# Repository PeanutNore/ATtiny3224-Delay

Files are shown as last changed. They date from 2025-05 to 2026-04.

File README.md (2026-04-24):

# ATtiny3224-Delay
A Digital Delay Pedal for guitar based on the ATtiny3224 microcontroller and 23LC512 SRAM

I have included two different circuit designs that are each compatible with the code in this repository.
I recommend the "Business Card Delay" circuit for those comfortable designing their own PCB as this is 
a newer, optimized design that provides better audio quality with fewer components.
If you don't want to design your own PCB you can order copies of version 1.0 using the included Gerber files.

This program, PCB design, and associated schematics are distributed in the hope that they will be useful, but WITHOUT ANY WARRANTY; without even the implied warranty of MERCHANTABILITY or FITNESS FOR A PARTICULAR PURPOSE.

ATtinyDelay

To use this software you will need:

- A complete and working ATtiny Delay circuit (or the version of the circuit on my business card)
    - Refer to the included schematic (or just populate the components on the business card)
    - Gerber files for ordering PCBs are included in ATTiny_Delay_Pedal.zip. I have had success using JLCPCB. This is not an endorsement, use whatever PCB vendor you prefer.
- Arduino IDE version 1.8.19 or greater
- megaTinyCore (https://github.com/SpenceKonde/megaTinyCore) for ATtiny3224 support
- A UPDI programmer (I recommend the UPDI Friend from Adafruit)

This is a basic digital delay pedal for guitar that aims achieve high audio quality at minimal cost compared to other DIY delay options such as using an FV-1 or PT2399.
It provides 12 bit sample depth at greater than 24khz sample rate, which results in no loss of quality when used with typical guitar and amp rigs.

 * Copyright 2025-2026 Samuel Brown. All Rights Reservered.
 * 
 * Licensed under Creative Commons CC-BY-NC-SA 4.0
 * https://creativecommons.org/licenses/by-nc-sa/4.0/
 * 
 * You are free to share and adapt this software for non-
 * commercial purposes provided that you give appropriate 
 * credit and attribution, and distribute your contributions 
 * under the same CC-BY-NC-SA license.
 * 
 * For commercial licensing contact sam.brown.rit08@gmail.com

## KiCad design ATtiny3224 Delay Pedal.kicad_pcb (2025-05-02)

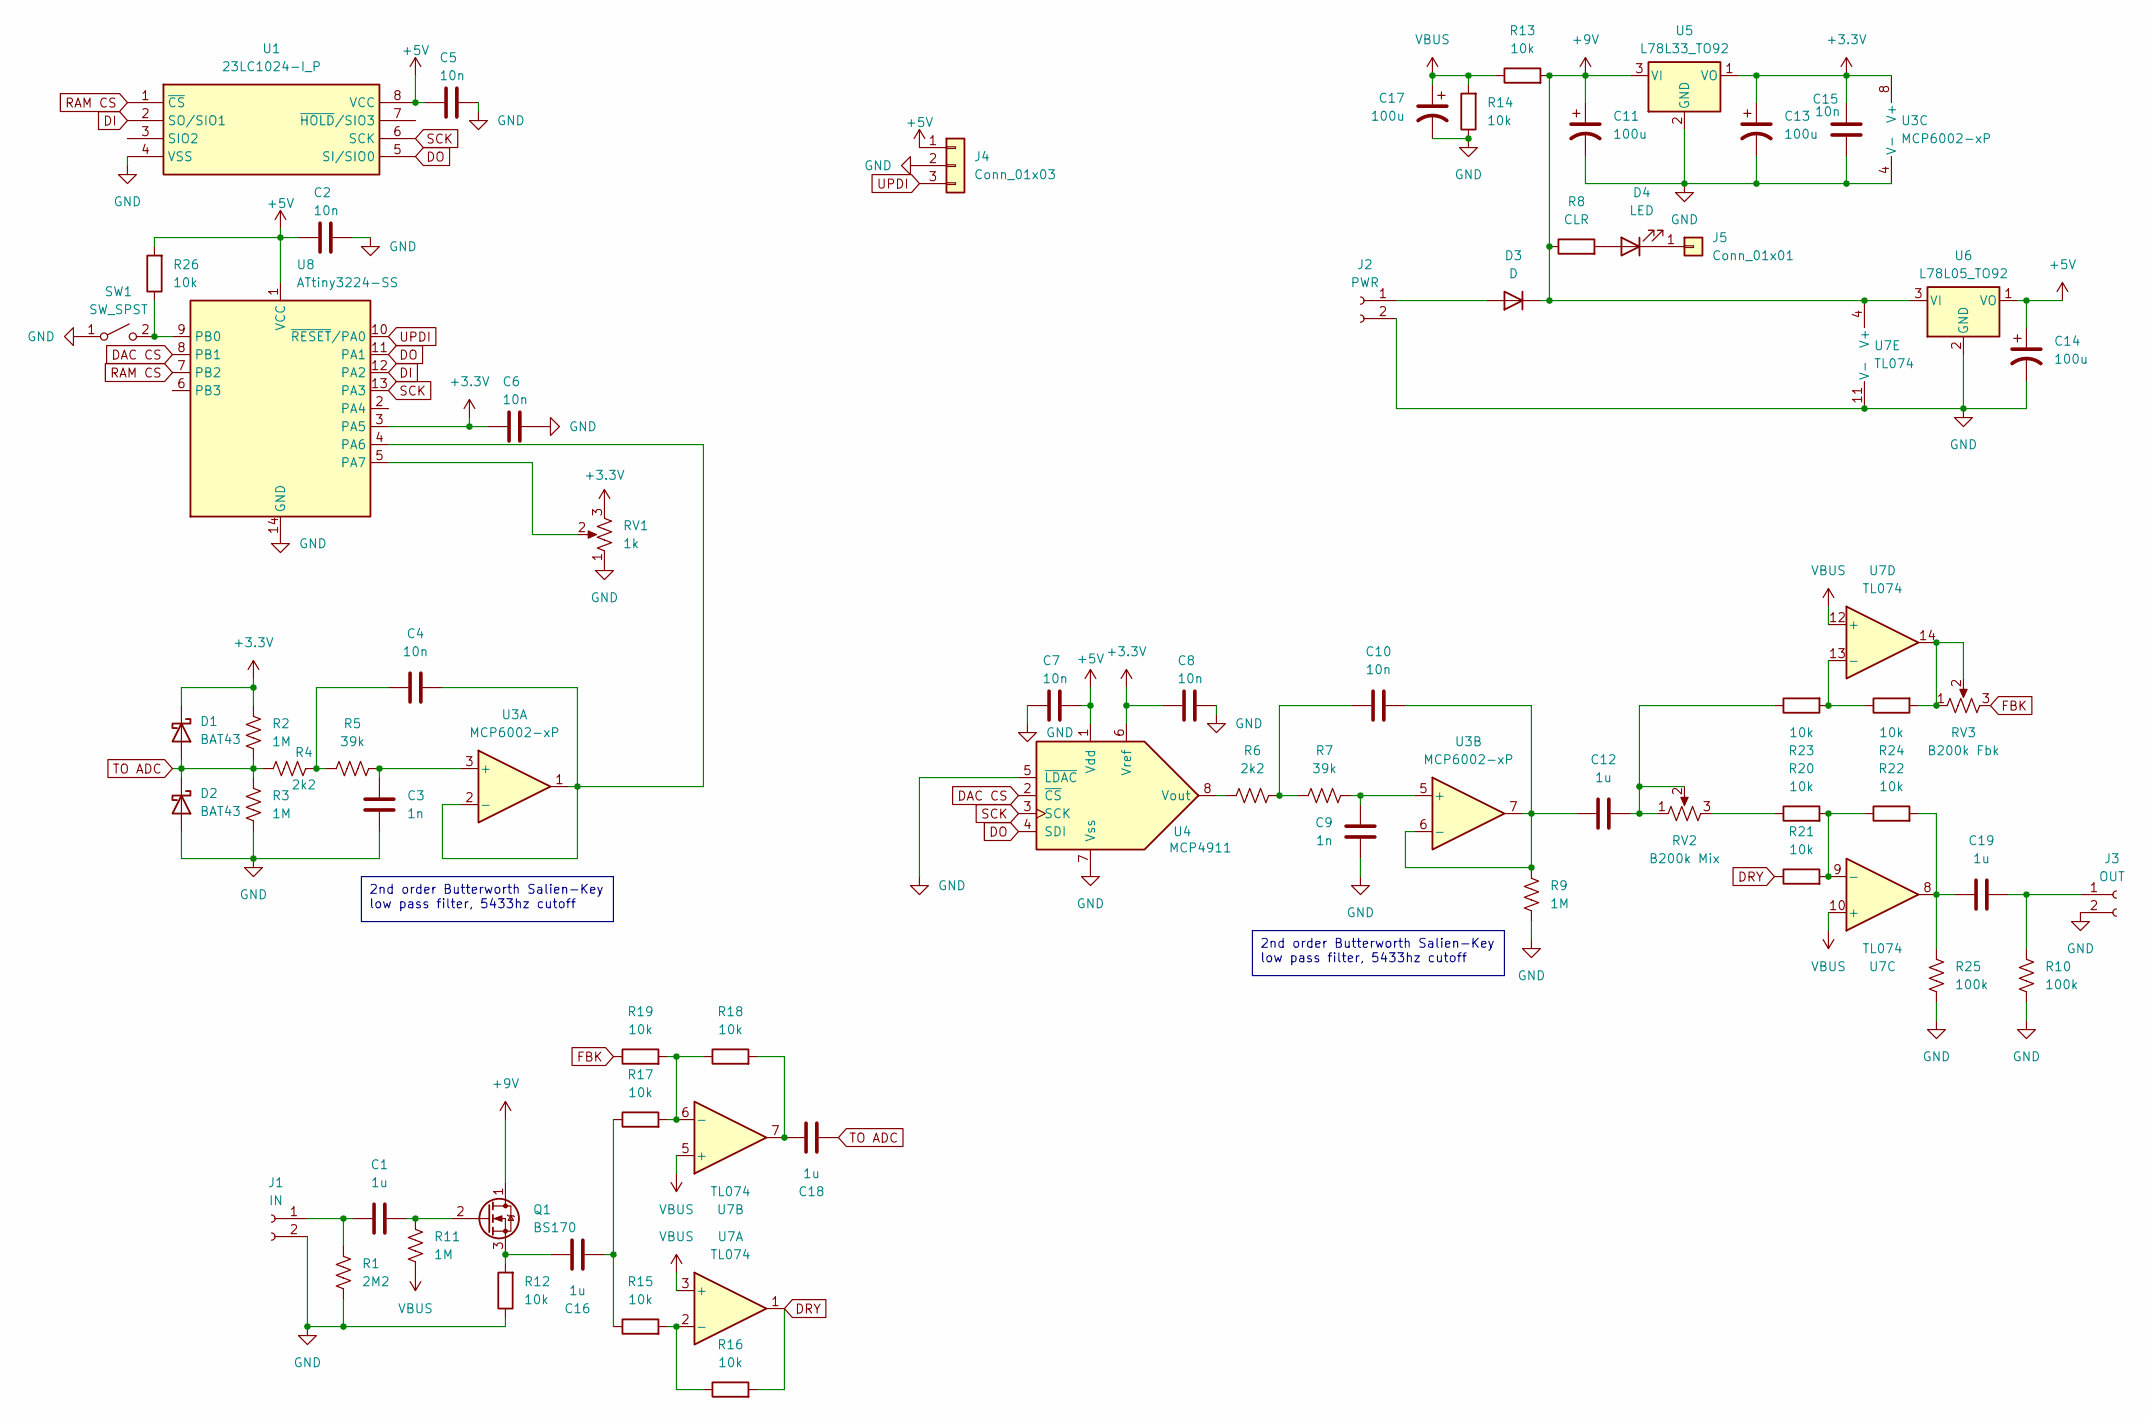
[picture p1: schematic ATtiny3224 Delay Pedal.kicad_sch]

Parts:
C1, C12, C16, C18, C19: 1u; C_Rect_L7.0mm_W4.5mm_P5.00mm
C2, C4, C5, C6, C7, C8, C10, C15: 10n; C_Rect_L4.0mm_W2.5mm_P2.50mm
C3, C9: 1n; C_Rect_L4.0mm_W2.5mm_P2.50mm
C11, C13, C14, C17: 100u; CP_Radial_D6.3mm_P2.50mm
D1, D2: BAT43; D_DO-35_SOD27_P7.62mm_Horizontal
D3: D; D_DO-35_SOD27_P7.62mm_Horizontal
D4: LED; LED_D3.0mm
J1: IN; PinHeader_1x02_P2.54mm_Vertical
J2: PWR; PinHeader_1x02_P2.54mm_Vertical
J3: OUT; PinHeader_1x02_P2.54mm_Vertical
J4: Conn_01x03; PinHeader_1x03_P2.54mm_Vertical
J5: Conn_01x01; PinHeader_1x01_P2.54mm_Vertical
Q1: BS170; TO-92_Inline
R1: 2M2; R_Axial_DIN0207_L6.3mm_D2.5mm_P7.62mm_Horizontal
R2, R3, R9, R11: 1M; R_Axial_DIN0207_L6.3mm_D2.5mm_P7.62mm_Horizontal
R4, R6: 2k2; R_Axial_DIN0207_L6.3mm_D2.5mm_P7.62mm_Horizontal
R5, R7: 39k; R_Axial_DIN0207_L6.3mm_D2.5mm_P7.62mm_Horizontal
R8: CLR; R_Axial_DIN0207_L6.3mm_D2.5mm_P7.62mm_Horizontal
R10, R25: 100k; R_Axial_DIN0207_L6.3mm_D2.5mm_P7.62mm_Horizontal
R12, R13, R14, R15, R16, R17, R18, R19, R20, R21, R22, R23, R24, R26: 10k; R_Axial_DIN0207_L6.3mm_D2.5mm_P7.62mm_Horizontal
RV1: 1k; RV16AF-41
RV2: B200k Mix; RV16AF-41
RV3: B200k Fbk; RV16AF-41
SW1: SW_SPST; PinHeader_1x03_P2.54mm_Vertical
U1: 23LC1024-I_P; SOIC-8_3.9x4.9mm_P1.27mm; Mouser Part Number 579-23LC1024-I/P
U3: MCP6002-xP; SOIC-8_3.9x4.9mm_P1.27mm
U4: MCP4911; SOIC-8_3.9x4.9mm_P1.27mm
U5: L78L33_TO92; TO-92_Inline
U6: L78L05_TO92; TO-92_Inline
U7: TL074; SOIC-14_3.9x8.7mm_P1.27mm
U8: ATtiny3224-SS; SOIC-14_3.9x8.7mm_P1.27mm

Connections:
+3.3V: C6.2, C8.2, C13.1, C15.1, D1.1 (K), R2.1, RV1.3, U3.8 (V+), U4.6 (Vref), U5.1 (VO), U8.3 (PA5)
+5V: C2.2, C5.2, C7.1, C14.1, J4.1, R26.2, U1.8 (VCC), U4.1 (Vdd), U6.1 (VO), U8.1 (VCC)
+9V: C11.1, D3.1 (K), Q1.1 (D), R8.1, R13.2, U5.3 (VI), U6.3 (VI), U7.4 (V+)
DAC CS: U4.2 (~CS), U8.8 (PB1)
DI: U1.2 (SO/SIO1), U8.12 (PA2)
DO: U1.5 (SI/SIO0), U4.4 (SDI), U8.11 (PA1)
DRY: R16.2, R21.1, U7.1
FBK: R19.1, RV3.3
GND: C2.1, C3.2, C5.1, C6.1, C7.2, C8.1, C9.2, C11.2, C13.2, C14.2, C15.2, C17.2, D2.2 (A), J1.2, J2.2, J3.2, J4.2, R1.2, R3.2, R9.2, R10.2, R12.1, R14.1, R25.2, RV1.1, SW1.1 (A), U1.4 (VSS), U3.4 (V-), U4.5 (~LDAC), U4.7 (Vss), U5.2 (GND), U6.2 (GND), U7.11 (V-), U8.14 (GND)
unnamed: C4.1, R4.2, R5.1
unnamed: C10.1, R6.2, R7.1
unnamed: C12.2, R23.1, RV2.1, RV2.2
unnamed: C16.2, R15.1, R17.1
unnamed: C18.1, R18.2, U7.7
unnamed: C19.1, R22.2, R25.1, U7.8
unnamed: D3.2 (A), J2.1
unnamed: D4.2 (A), R8.2
unnamed: D4.1 (K), J5.1
unnamed: C1.1, J1.1, R1.1
unnamed: C19.2, J3.1, R10.1
unnamed: C1.2, Q1.2 (G), R11.1
unnamed: C16.1, Q1.3 (S), R12.2
unnamed: R20.1, RV2.3
unnamed: R24.2, RV3.1, RV3.2, U7.14
unnamed: R26.1, SW1.2 (B), U8.9 (PB0)
unnamed: C3.1, R5.2, U3.3 (+)
unnamed: C4.2, U3.1, U3.2 (-), U8.4 (PA6)
unnamed: C9.1, R7.2, U3.5 (+)
unnamed: C10.2, C12.1, R9.1, U3.6 (-), U3.7
unnamed: R6.1, U4.8 (Vout)
unnamed: R15.2, R16.1, U7.2 (-)
unnamed: R17.2, R18.1, R19.2, U7.6 (-)
unnamed: R20.2, R21.2, R22.1, U7.9 (-)
unnamed: R23.2, R24.1, U7.13 (-)
unnamed: RV1.2, U8.5 (PA7)
RAM CS: U1.1 (~CS), U8.7 (PB2)
SCK: U1.6 (SCK), U4.3 (SCK), U8.13 (PA3)
TO ADC: C18.2, D1.2 (A), D2.1 (K), R2.2, R3.1, R4.1
UPDI: J4.3, U8.10 (~RESET/PA0)
VBUS: C17.1, R11.2, R13.1, R14.2, U7.3 (+), U7.5 (+), U7.10 (+), U7.12 (+)

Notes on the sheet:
2nd order Butterworth Salien-Key low pass filter, 5433hz cutoff

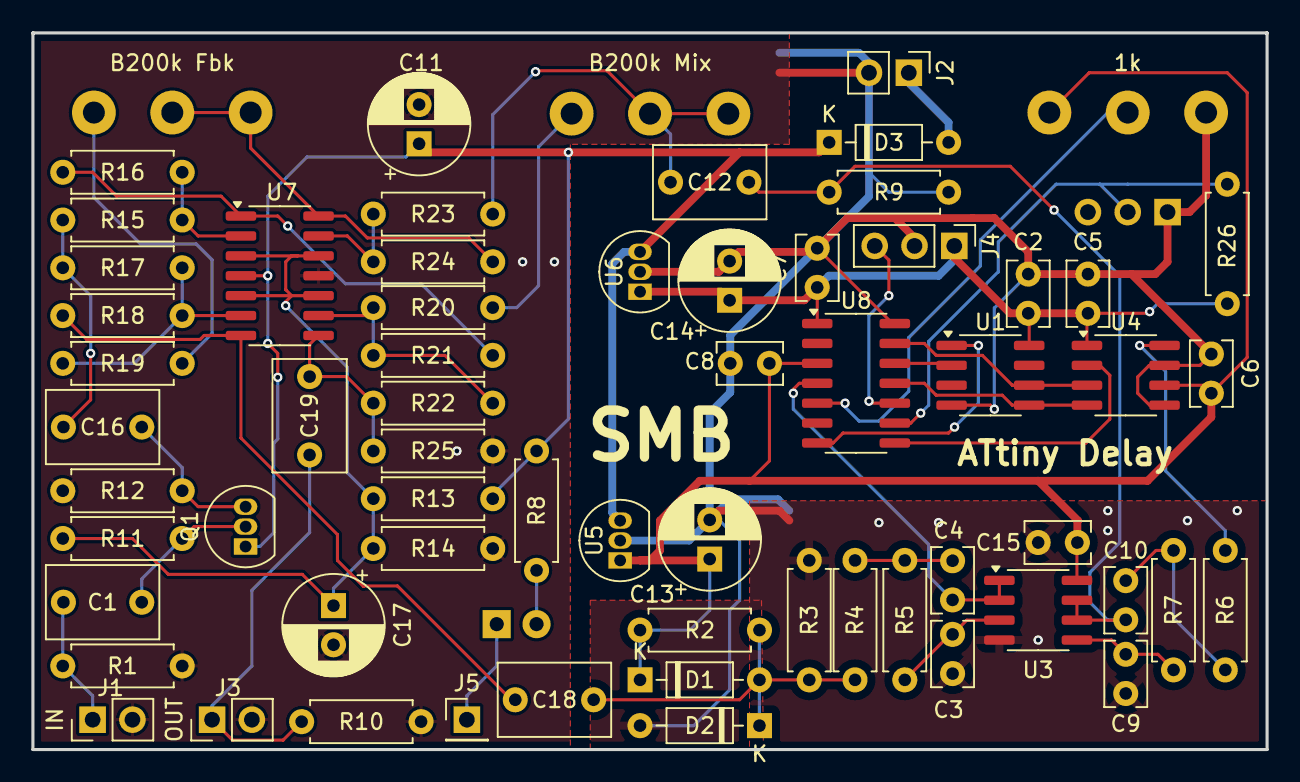
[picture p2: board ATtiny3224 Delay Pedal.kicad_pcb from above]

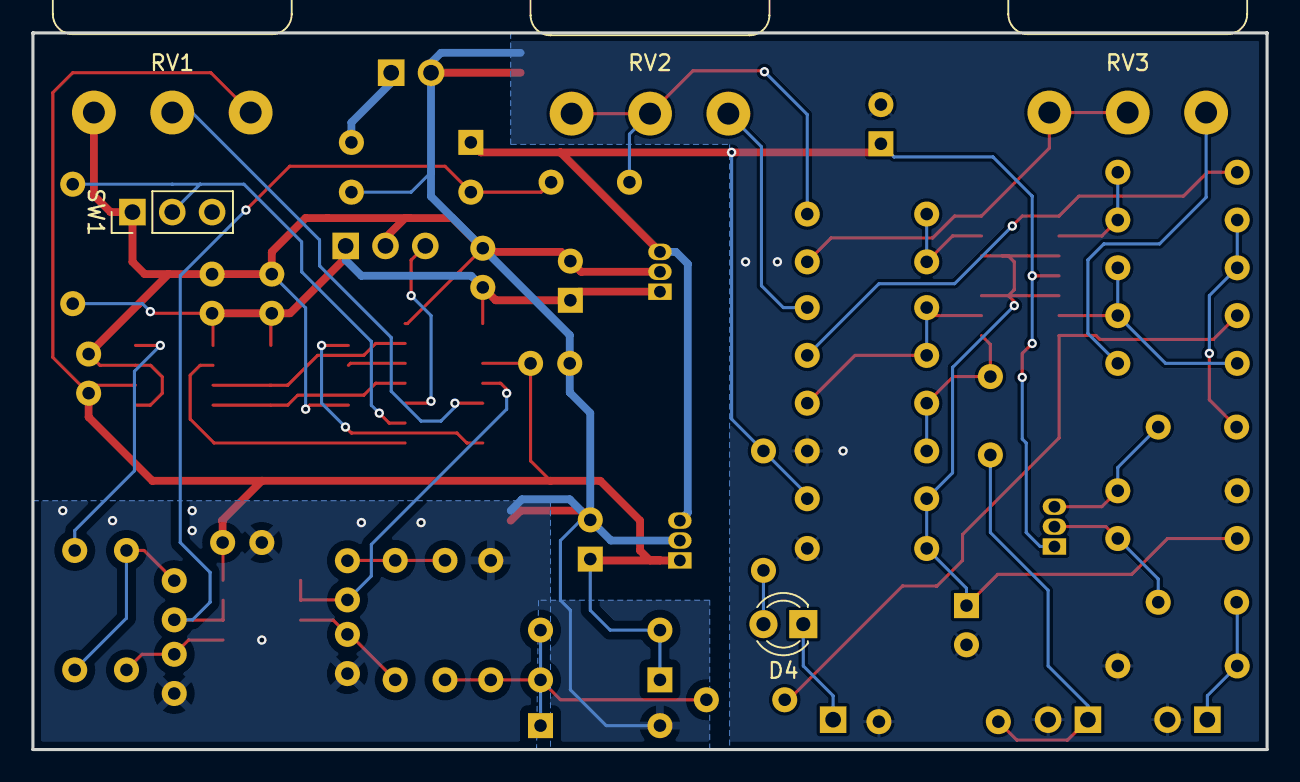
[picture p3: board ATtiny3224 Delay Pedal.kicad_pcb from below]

Board: 2 copper layers, 78.7 x 45.7 mm, 66 parts (5 on the bottom side), 40 nets.

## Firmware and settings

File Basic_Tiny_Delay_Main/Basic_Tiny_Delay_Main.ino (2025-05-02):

#include "SPI.h"


//IO Pins
const uint8_t InputPin = PIN_PA6;
const uint8_t TimePin = PIN_PA7;
const uint8_t ModePin = PIN_PB0;
const uint8_t RAM_CS = PIN_PB2;
const uint8_t DAC_CS = PIN_PB1;

//Audio Samples
volatile uint16_t sampleIn = 2047;
volatile uint16_t sampleOut = 2047;
volatile uint8_t sampleBuf[2] = {7, 255};

//Step Counters
volatile uint16_t sampleStep = 0;
volatile uint16_t delayStep = 0;

//Controls
volatile uint16_t delayTime = 32768;
volatile uint16_t targetTime = 32768;
volatile uint16_t extraClocks = 0;

//SPI
uint32_t _SPIspeed = 20000000;
SPISettings _spi_settings;

ISR(TCA0_OVF_vect) {                                        //runs each time the TCA0 periodic interrupt triggers
  TCA0.SINGLE.INTFLAGS = TCA_SINGLE_OVF_bm;                 //clear the interrupt flags
  
  //read the input
  sampleIn = analogRead(InputPin);
  ADC0.MUXPOS = ((TimePin & 0x7F) << ADC_MUXPOS_gp);
    
  if (!(digitalReadFast(ModePin))){targetTime = targetTime << 4;} //multiplies by 16 (max 65408)
  else {targetTime = targetTime << 3;}                            //multiplies by 8 (max 32704)
  targetTime += 128;                                             //shift max to 65536
  if (delayTime < targetTime){delayTime += 2;}
  if (delayTime > targetTime){delayTime -= 2;}
  delayStep = sampleStep - delayTime;
  
  //read the delayed sample from RAM
  sampleOut = 0x3000;
  digitalWriteFast(RAM_CS, LOW);
  SPI.beginTransaction(_spi_settings);
  SPI.transfer(0x03);     //command READ
  SPI.transfer((uint8_t)((delayStep >> 8) & 0xFF)); //send top half of address to read
  SPI.transfer((uint8_t)(delayStep & 0xFF));        //send bottom half of address
  sampleOut |= (SPI.transfer(0xFF) << 8);           //send a dummy byte to get back the top half of sample
  sampleOut |= SPI.transfer(0xFF);                  //send a dummy byte to get back the bottom half of sample
  digitalWriteFast(RAM_CS, HIGH);

  //send the delayed sample to the DAC
  digitalWriteFast(DAC_CS, LOW);
  SPI.transfer((uint8_t)((sampleOut >> 8) & 0xFF));
  SPI.transfer((uint8_t)(sampleOut & 0xFF));
  digitalWriteFast(DAC_CS, HIGH);
  
  //store the newest sample in RAM
  digitalWriteFast(RAM_CS, LOW);
  SPI.transfer(0x02);        //command WRITE
  SPI.transfer((uint8_t)((sampleStep >> 8) & 0xFF));  //top half of adddress to write
  SPI.transfer((uint8_t)(sampleStep & 0xFF));         //bottom half of address to write
  SPI.transfer((uint8_t)((sampleIn >> 8) & 0xFF));    //top half of sample to store
  SPI.transfer((uint8_t)(sampleIn & 0xFF));           //bottom half of sample
  SPI.endTransaction();
  digitalWriteFast(RAM_CS, HIGH);

  //increment the step counter by 2 (since we're writing 2 bytes at a time), rolls over on its own at 65536
  sampleStep += 2;
  targetTime = analogRead(TimePin) & 0xFFF8;                     //masks the 3 LSBs for noise reduction (max 4088)
  ADC0.MUXPOS = ((InputPin & 0x7F) << ADC_MUXPOS_gp);
}

void setup() {
  //basic startup
  pinMode(InputPin, INPUT);
  pinMode(TimePin, INPUT);
  pinMode(ModePin, INPUT);
  pinMode(RAM_CS, OUTPUT);
  pinMode(DAC_CS, OUTPUT);
  digitalWriteFast(RAM_CS, HIGH);
  digitalWriteFast(DAC_CS, HIGH);
  //setup SPI and RAM chip
  SPI.begin();
  _spi_settings = SPISettings(_SPIspeed, MSBFIRST, SPI_MODE0);
  SPI.usingInterrupt(TCA0_OVF_vect);
  digitalWriteFast(RAM_CS, LOW);
  SPI.beginTransaction(_spi_settings);
  SPI.transfer(0b00000001);       //command WRMR (write mode register)
  SPI.transfer(0b01000000); //sequential mode
  SPI.endTransaction();
  digitalWriteFast(RAM_CS, HIGH);
  //fill RAM with 2047s
  digitalWriteFast(RAM_CS, LOW);
  SPI.beginTransaction(_spi_settings);
  SPI.transfer(0x02);       //command WRITE
  SPI.transfer((uint8_t) 0x00);
  SPI.transfer((uint8_t) 0x00);
  for (uint32_t i; i < 65536; i++){
    SPI.transfer((uint8_t)((sampleOut >> 8) & 0xFF));
    SPI.transfer((uint8_t)(sampleOut & 0xFF));
  }
  SPI.endTransaction();
  digitalWriteFast(RAM_CS, HIGH);

  //setup ADC
  analogReference(EXTERNAL);
  analogReadResolution(12);
  analogSampleDuration(3);
  analogClockSpeed(3000);
  delayTime = analogRead(TimePin) & 0xFFF8;                     //masks the 3 LSBs for noise reduction (max 4088)
  ADC0.MUXPOS = ((InputPin & 0x7F) << ADC_MUXPOS_gp);
  
  
  //setup interrupt timing for desired sample rate
  takeOverTCA0();
  TCA0.SINGLE.INTFLAGS = TCA_SINGLE_OVF_bm;       //clears the flags
  TCA0.SINGLE.INTCTRL = 0b00000001;               //overflow interrupt every PER cycles
  TCA0.SINGLE.CTRLA = TCA_SINGLE_CLKSEL_DIV1_gc;  //Clock prescaler / 1 (20 MHz)    
  TCA0.SINGLE.PER = 1000;                          //ADJUST SAMPLE RATE HERE: Currently 625 clocks = 32ksps. 1000 clocks = 20ksps
  TCA0.SINGLE.CTRLA |= 1;                         //Enables the timer
}

void loop() {
  // there is no main loop, after setup everything happens within the ISR

}

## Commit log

2026-03-17 Update ATtiny Delay circuit instructions in README
    Clarified circuit requirements and added reference to business card.
2026-04-24 Enhance README with circuit design recommendations
    Added details about circuit designs and PCB options.
2026-04-24 Enhance README with circuit design information
    Added a brief introduction about circuit designs and recommendations.
